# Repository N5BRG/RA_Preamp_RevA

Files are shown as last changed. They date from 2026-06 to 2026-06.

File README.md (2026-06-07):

# RA_Preamp_RevA

Copyright (c) 2026 Robert S. Stricklin Jr

This hardware design is licensed under the CERN Open Hardware Licence Version 2 - Permissive (CERN-OHL-P-2.0).

You may obtain a copy of the license in the `LICENSE` file included with this repository.

## Overview

This design is a Radio Astronomy Preamplifier intended for operation at 1420 MHz, which is approximately the frequency of the neutral hydrogen spectral line produced by the hyperfine spin-flip transition of hydrogen atoms in space. This signal is commonly referred to as the **Hydrogen Line** or the **21-centimeter Hydrogen Line**.

The goal of this preamplifier is to provide the lowest practical noise figure while amplifying extremely low-level radio signals. Included in the design is a PIN diode switch that allows switching between the antenna input and an alternate path terminated with a precision 50-ohm reference resistor. This approach is similar to the Dicke switching technique developed by [Robert H. Dicke](https://en.wikipedia.org/wiki/Robert_H._Dicke) in the mid-1940s for microwave radiometry and receiver calibration.

For best performance, the preamplifier is powered from a low-noise 5-volt power supply (5.5 V maximum). The PIN diode switch is controlled by an external voltage of approximately 1.8 to 2.5 volts applied to the control input for the ON state (3.3 V maximum), and 0 V to -20 mV for the OFF state. The analog RF ground and the digital switching ground are separated to minimize the possibility of switching noise coupling into the RF signal path.

The total current required by the preamplifier is approximately 160 mA, although this value may vary somewhat with temperature and component tolerances. At 5 volts and 160 mA, the power dissipation is approximately 800 mW at 25°C, so good thermal management should be considered when mounting the preamplifier in an enclosure.

The PCB is designed to plug into a power and control PCB. However, because the power board is longer, it may be more practical to mount the boards side-by-side if the power board is used. To minimize noise, a low-noise linear voltage regulator is recommended.

A graph showing the noise figure versus frequency, along with the gain of the preamplifier, is included with the project files. These measurements were obtained using an HP 8970B Noise Figure Meter. The 1420 MHz noise figure is 0.46 dB and the gain is 40.11 dB.

## Amateur Radio Astronomy

This design was created to support the educational and scientific goals of the Society of Amateur Radio Astronomers (SARA). Additional information about SARA can be found at:

https://www.radio-astronomy.org/

Many of the ideas incorporated into this design were discussed during SARA's regular monthly Zoom meetings and educational activities.

If you enjoy physics, astronomy, radio astronomy, electronics, and scientific experimentation, please consider joining SARA and participating in its programs. SARA is an especially good opportunity for students and young people who are interested in science, engineering, and technology. Most participation is conducted online through video conference meetings.

## Acknowledgements

If you use KiCad, please consider making a donation to the project to help support the continuing development and distribution of this outstanding open-source electronic design software.

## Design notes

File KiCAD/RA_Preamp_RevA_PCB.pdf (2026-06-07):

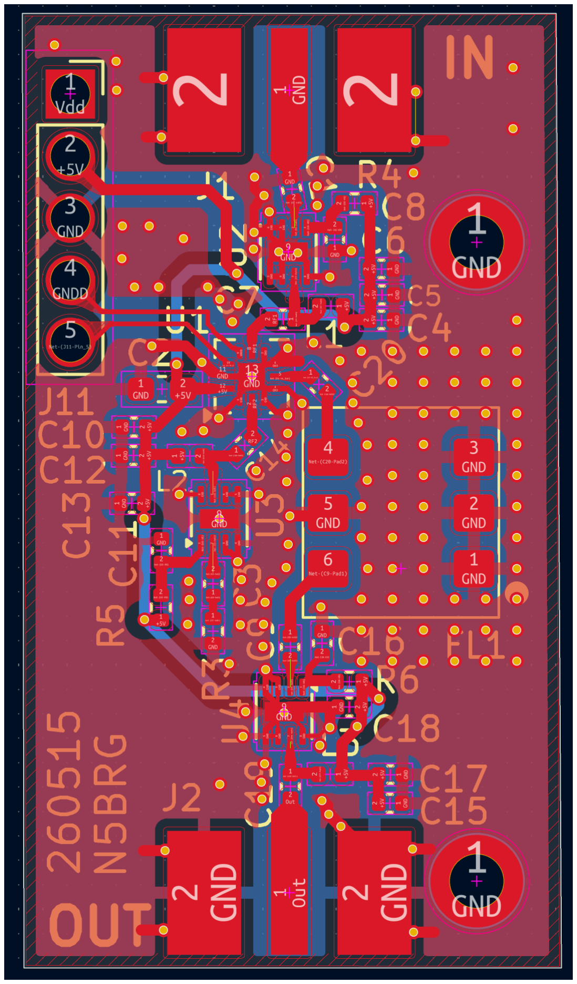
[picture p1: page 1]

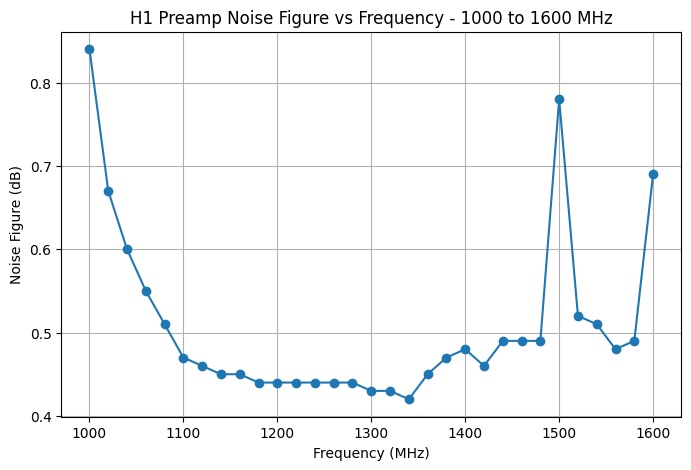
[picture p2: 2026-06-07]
H1_Preamp_NoiseFigure_vs_Frequency_REPLOT_zoom.jpg

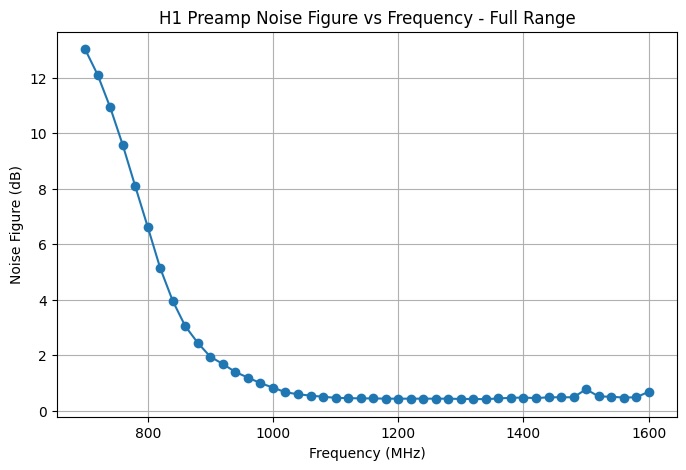
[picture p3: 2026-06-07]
H1_Preamp_NoiseFigure_vs_Frequency_REPLOT_full.jpg

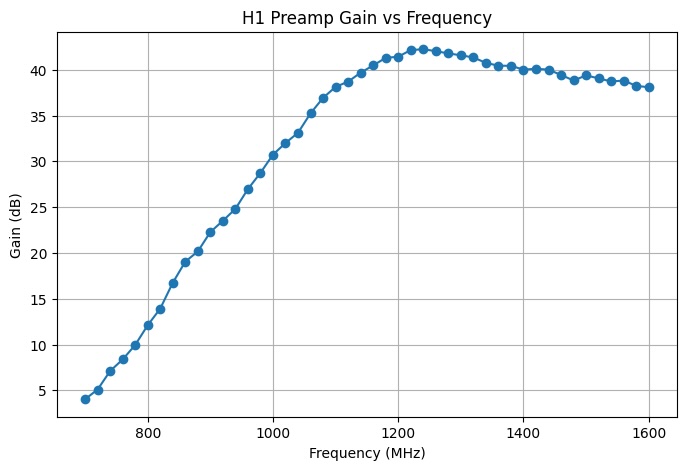
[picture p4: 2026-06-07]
H1_Preamp_Gain_vs_Frequency.jpg

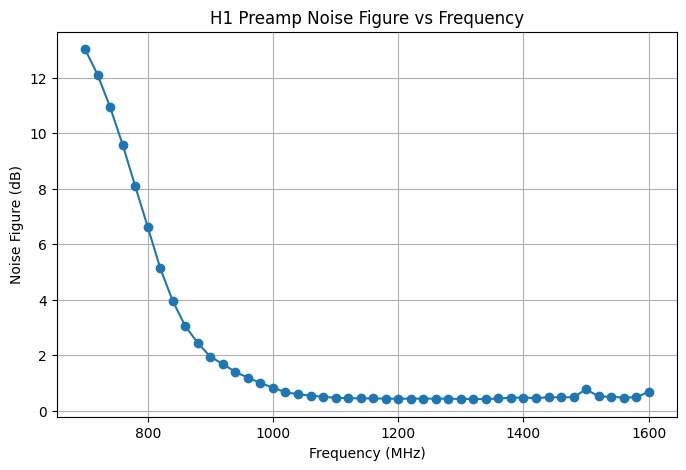
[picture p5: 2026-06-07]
H1_Preamp_NoiseFigure_vs_Frequency.jpg

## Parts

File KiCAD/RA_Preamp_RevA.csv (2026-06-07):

Source: | /Volumes/Public/Projects/KiCAD PCBs/H1_RF2_C/H1_RF2_C.kicad_sch
Date: | 2026-04-18T14:53:34
Tool: | Eeschema 9.99.0-5271-ge2e5514f9b
Generator: | /Applications/KiCad/KiCad.app/Contents/SharedSupport/plugins/bom_csv_grouped_by_value_with_fp.py
Component Count: | 34
Ref | Qnty | Value | Cmp name | Footprint | Description | Vendor | DNP
C1, C3, C7, C9, C14, C19 | 6 | 22p | C | Capacitor_SMD:C_0402_1005Metric | Unpolarized capacitor
C2 | 1 | 100p | C | Capacitor_SMD:C_0603_1608Metric_Pad1.08x0.95mm_HandSolder | Unpolarized capacitor
C4, C10, C15 | 3 | 10p | C | Capacitor_SMD:C_0402_1005Metric | Unpolarized capacitor
C5, C12, C17 | 3 | 1u | C | Capacitor_SMD:C_0402_1005Metric | Unpolarized capacitor
C6, C13, C18 | 3 | 100p | C | Capacitor_SMD:C_0402_1005Metric | Unpolarized capacitor
C8, C11, C16 | 3 | 0.1u | C | Capacitor_SMD:C_0402_1005Metric | Unpolarized capacitor
FL1 | 1 | SYBP-1420+ | SYBP-1420+ | Bob:PL-308 | Band Pass Filter 1250 to 1560 MHz
J1 | 1 | Antenna | Antenna | Bob:SMA_WIDE_GND_EdgeMount_Small | Antenna
J2 | 1 | SMA | Conn_Coaxial_Small | Bob:SMA_WIDE_GND_EdgeMount_Small | small coaxial connector (BNC, SMA, SMB, SMC, Cinch/RCA, LEMO, ...)
J11 | 1 | Conn_01x04_Pin | Conn_01x05_Pin | Connector_PinSocket_2.54mm:PinSocket_1x05_P2.54mm_Vertical | Generic connector, single row, 01x05, script generated
L1, L2, L3 | 3 | 18n | L | Inductor_SMD:L_0402_1005Metric | Inductor
R3 | 1 | 50 | R | Resistor_SMD:R_0402_1005Metric | Resistor
R4, R5, R6 | 3 | 3.32K | R | Resistor_SMD:R_0402_1005Metric | Resistor
U1 | 1 | JSW2-63VHDRG+ | JSW2-63VHDRG+ | Bob:MT2140_With_polygons_custompads | SPDT RF Switch Insuration loss 0.4 dB @ 3G
U2, U3, U4 | 3 | QPL9547 | QPL9547 | Package_DFN_QFN:DFN-8-1EP_2x2mm_P0.5mm_EP0.8x1.6mm | 100-6000MHz RF/IF +19.5dB gain block, DFN-8

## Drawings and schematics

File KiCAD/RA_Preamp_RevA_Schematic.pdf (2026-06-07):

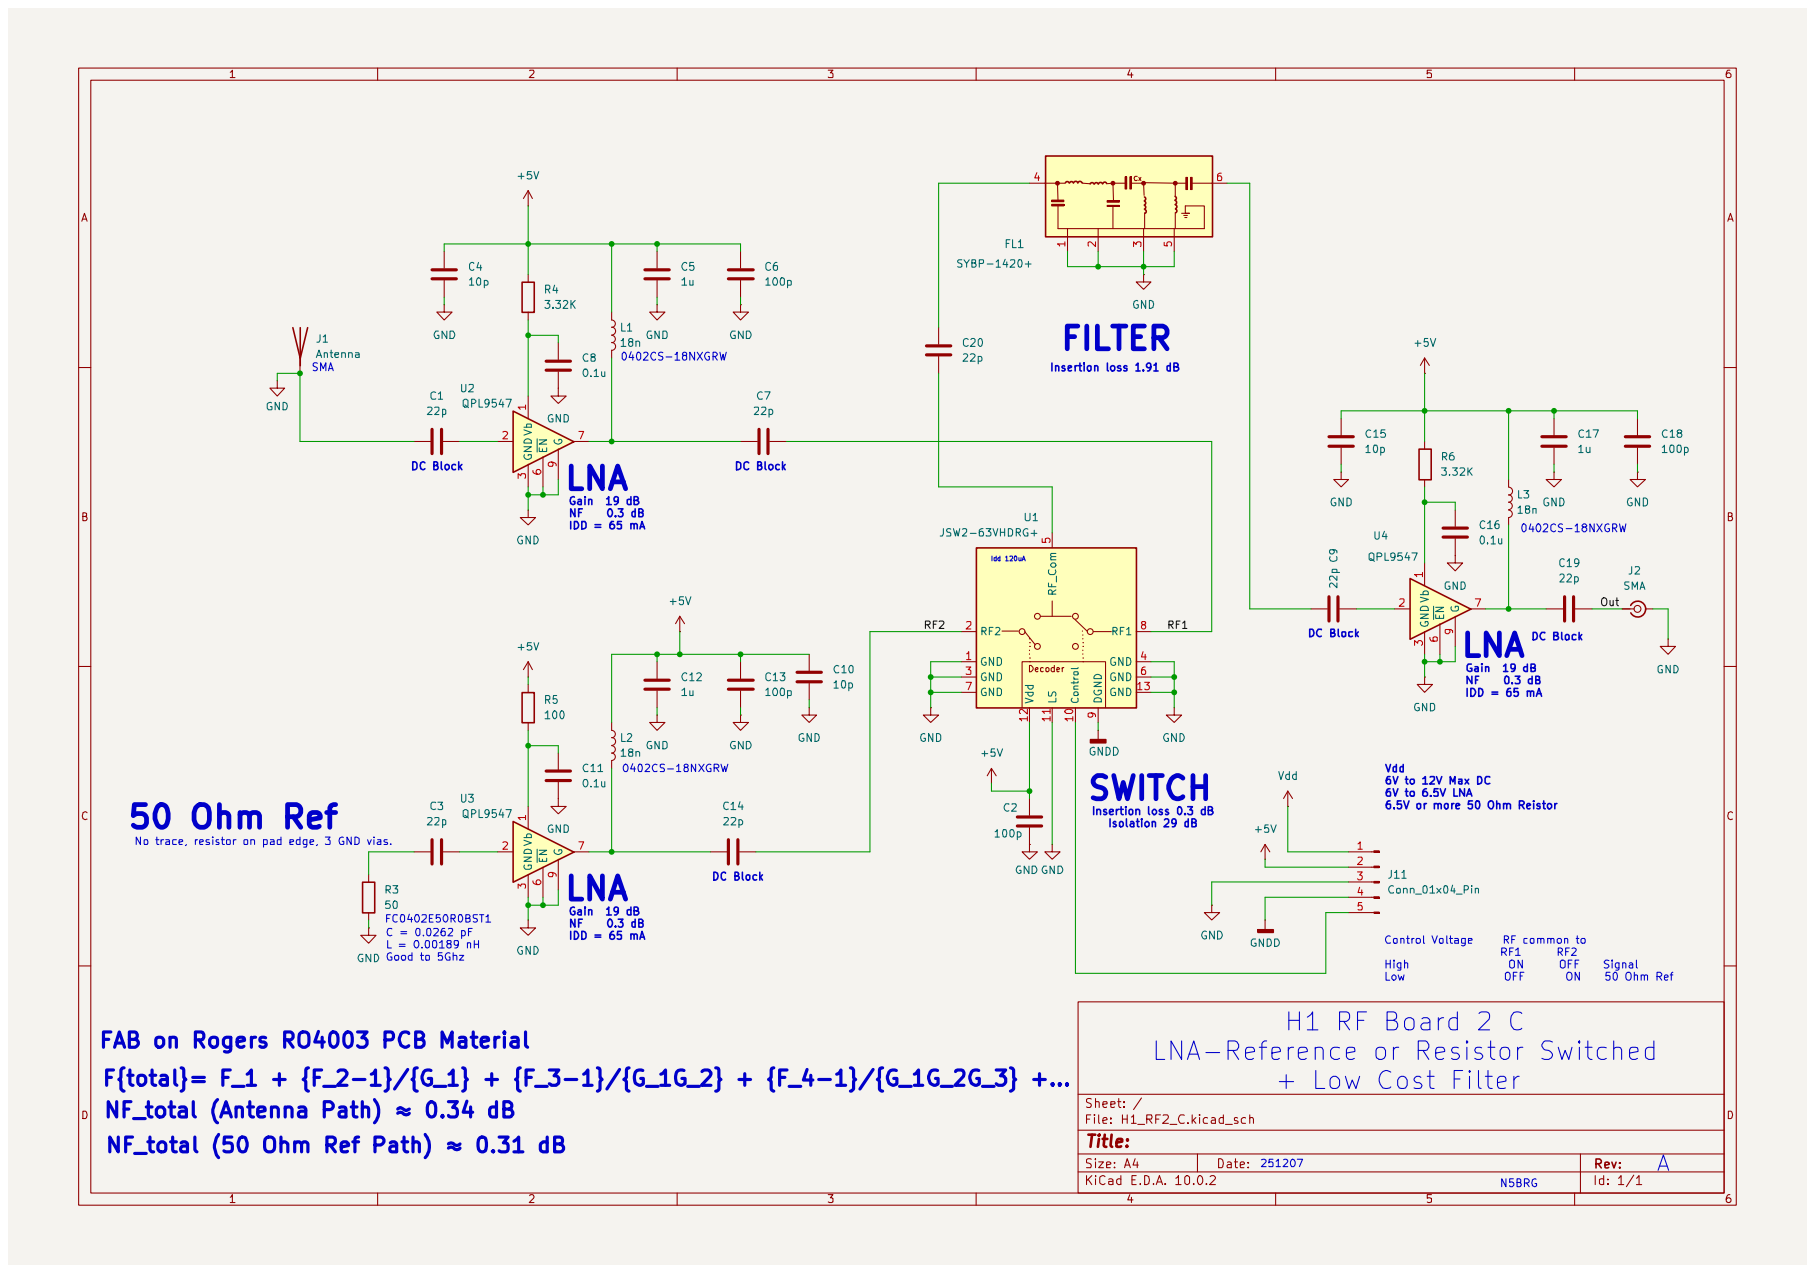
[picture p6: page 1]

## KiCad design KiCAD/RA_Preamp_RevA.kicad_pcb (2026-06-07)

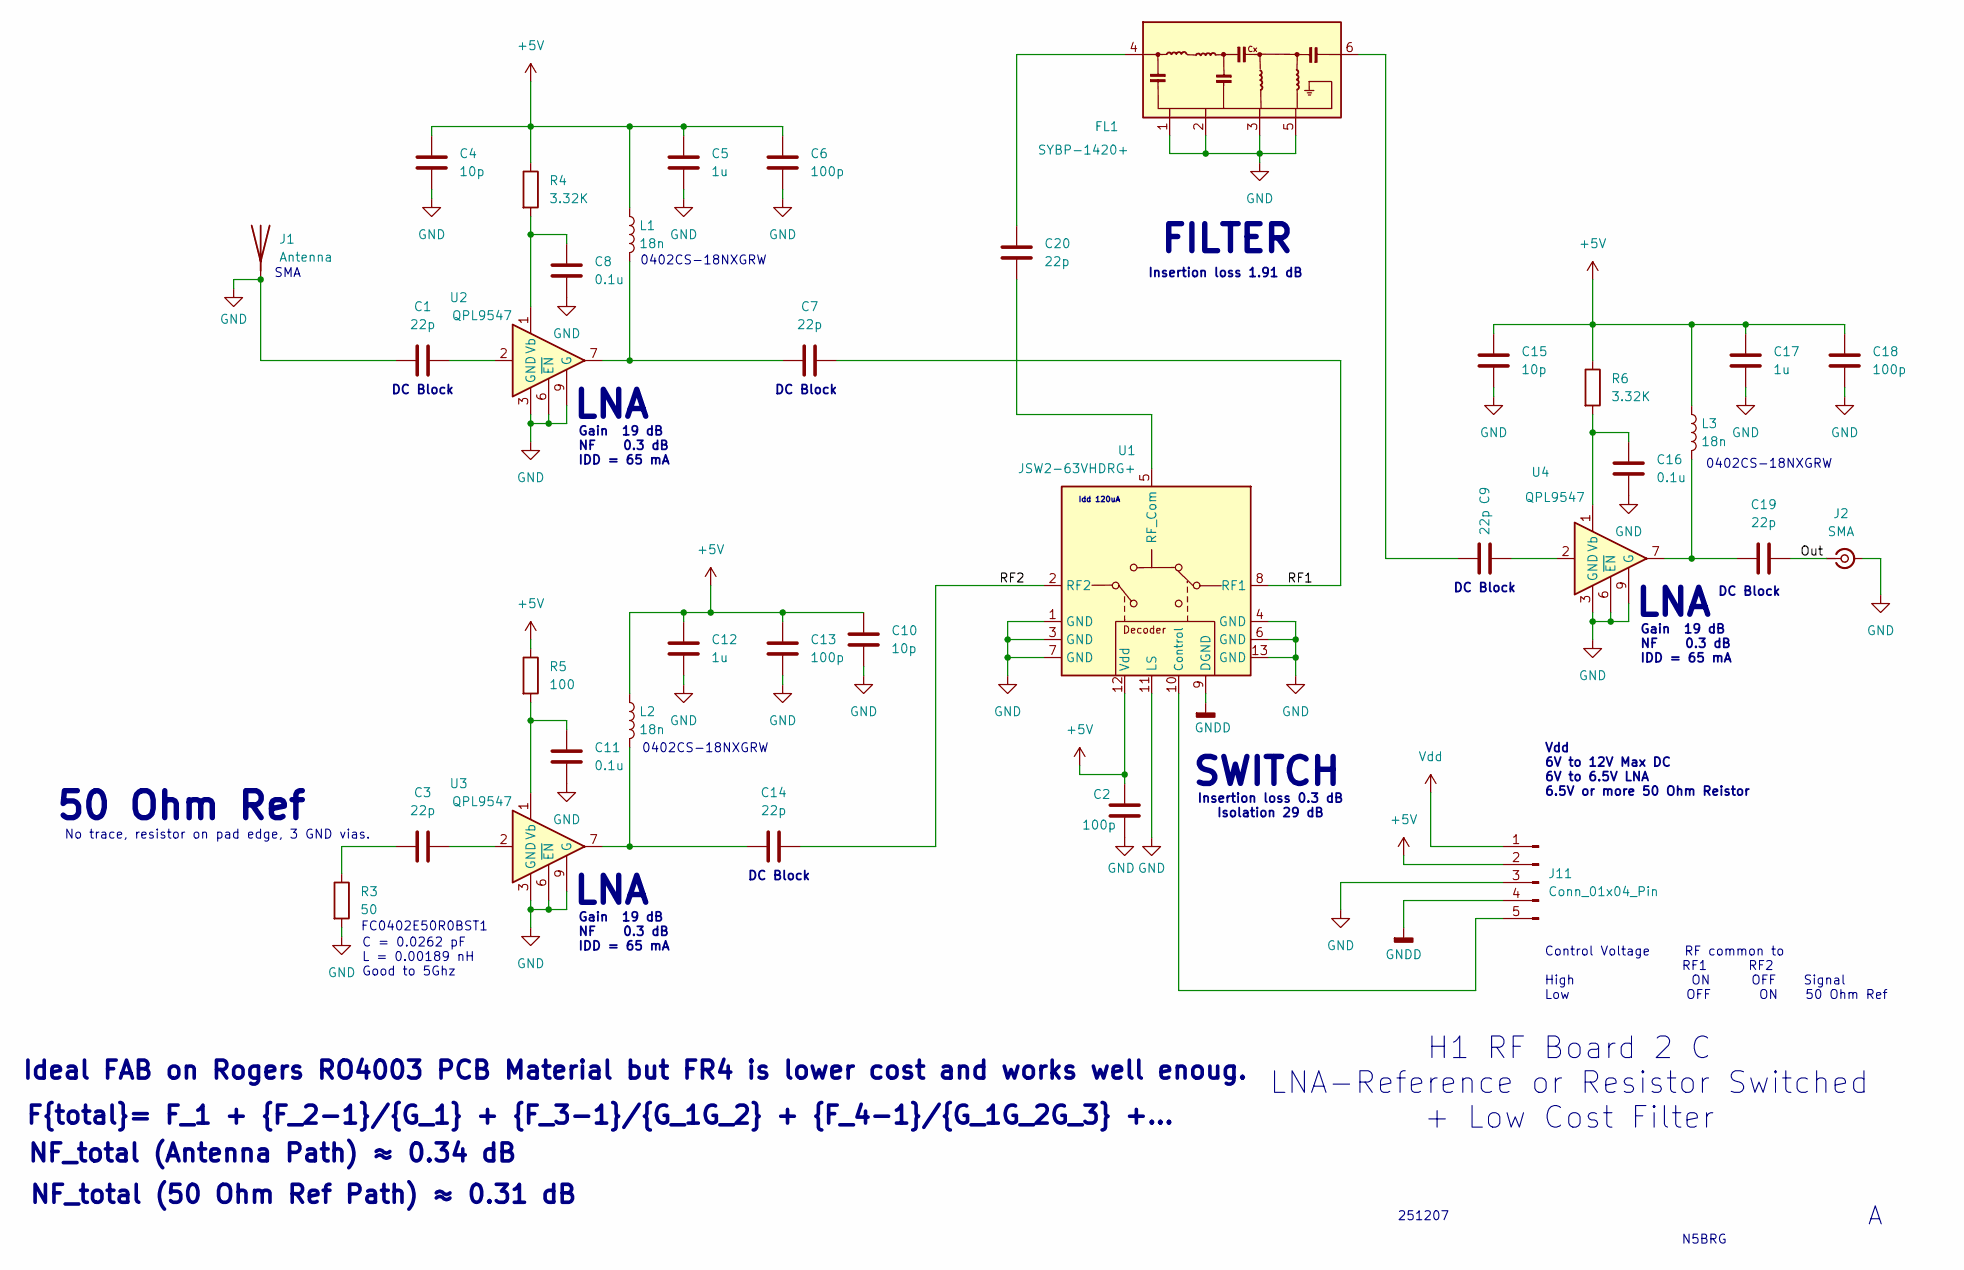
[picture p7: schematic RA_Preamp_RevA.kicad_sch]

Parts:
C1, C3, C7, C9, C14, C19, C20: 22p; C_0402_1005Metric; MPN 0402YK220FBWTR
C2: 100p; C_0603_1608Metric_Pad1.08x0.95mm_HandSolder; MPN GCM1555C1H101FA16J
C4, C10, C15: 10p; C_0402_1005Metric; MPN C0402C100K4RACAUTO
C5, C12, C17: 1u; C_0402_1005Metric; MPN C0402C105K4PACTU
C6, C13, C18: 100p; C_0402_1005Metric; MPN GCM1555C1H101FA16J
C8, C11, C16: 0.1u; C_0402_1005Metric; MPN CC0402KRX7R7BB104
FL1: SYBP-1420+; PL-308; MPN Do Not Populate
J1: Antenna; SMA_WIDE_GND_EdgeMount_Small; MPN SMA Connector Board Edge
J2: SMA; SMA_WIDE_GND_EdgeMount_Small; MPN TBD SMA Connector Board Edge
J11: Conn_01x04_Pin; PinSocket_1x05_P2.54mm_Vertical; MPN 1001-0-15-15-30-27-04-0 (5X)
L1, L2, L3: 18n; L_0402_1005Metric; MPN 0402CS-18NXGRW
R3: 50; R_0402_1005Metric; MPN FC0402E50R0BST1
R4, R6: 3.32K; R_0402_1005Metric; MPN RC0402JR-073K3L
R5: 100; R_0402_1005Metric; MPN RC0402JR-073K3L
U1: JSW2-63VHDRG+; MT2140_With_polygons_custompads; MPN JSW2-63VHDRG+
U2, U3, U4: QPL9547; DFN-8-1EP_2x2mm_P0.5mm_EP0.8x1.6mm; MPN QPL9547TR7

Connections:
+5V: C2.2, C4.2, C5.2, C6.2, C10.2, C12.2, C13.2, C15.2, C17.2, C18.2, J11.2, L1.1, L2.1, L3.1, R4.1, R5.1, R6.1, U1.12 (Vdd)
/Out: C19.2, J2.1 (In)
/RF1: C7.2, U1.8 (RF1)
/RF2: C14.2, U1.2 (RF2)
GND: C1.1, C2.1, C4.1, C5.1, C6.1, C8.1, C10.1, C11.1, C12.1, C13.1, C15.1, C16.1, C17.1, C18.1, FL1.1 (GND), FL1.2 (GND), FL1.3 (GND), FL1.5 (GND), J1.1 (A_1), J2.2 (Ext), J11.3, R3.2, U1.1 (GND), U1.3 (GND), U1.4 (GND), U1.6 (GND), U1.7 (GND), U1.11 (LS), U1.13 (GND), U2.3 (GND), U2.4 (GND), U2.5 (GND), U2.6 (~EN), U2.8 (GND), U2.9 (GND), U3.3 (GND), U3.4 (GND), U3.5 (GND), U3.6 (~EN), U3.8 (GND), U3.9 (G), U4.3 (GND), U4.4 (GND), U4.5 (GND), U4.6 (~EN), U4.8 (GND), U4.9 (GND); also elsewhere on the board
GNDD: J11.4, U1.9 (DGND)
unnamed: C1.2, U2.2
unnamed: C3.1, R3.1
unnamed: C3.2, U3.2
unnamed: C7.1, L1.2, U2.7
unnamed: C9.1, FL1.6
unnamed: C9.2, U4.2
unnamed: C14.1, L2.2, U3.7
unnamed: C19.1, L3.2, U4.7
unnamed: C20.2, FL1.4
unnamed: J11.5, U1.10 (Control)
unnamed: C20.1, U1.5 (RF_Com)
unnamed: C8.2, R4.2, U2.1 (Vb)
unnamed: C11.2, R5.2, U3.1 (Vb)
unnamed: C16.2, R6.2, U4.1 (Vb)
Vdd: J11.1

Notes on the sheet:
F{total}= F_1 + {F_2-1}/{G_1} + {F_3-1}/{G_1G_2} + {F_4-1}/{G_1G_2G_3} +...
FILTER
N5BRG
0402CS-18NXGRW
DC Block
LNA
251207
FC0402E50R0BST1
Gain 19 dB NF 0.3 dB IDD = 65 mA
NF_total (50 Ohm Ref Path) ≈ 0.31 dB
SMA
No trace, resistor on pad edge, 3 GND vias.
Vdd 6V to 12V Max DC 6V to 6.5V LNA 6.5V or more 50 Ohm Reistor
Idd 120uA
50 Ohm Ref
Insertion loss 1.91 dB
Insertion loss 0.3 dB Isolation 29 dB
NF_total (Antenna Path) ≈ 0.34 dB
C = 0.0262 pF L = 0.00189 nH Good to 5Ghz
SWITCH
H1 RF Board 2 C LNA-Reference or Resistor Switched + Low Cost Filter
Ideal FAB on Rogers RO4003 PCB Material but FR4 is lower cost and works well enoug.
Control Voltage RF common to RF1 RF2 High ON OFF Signal Low OFF ON 50 Ohm Ref

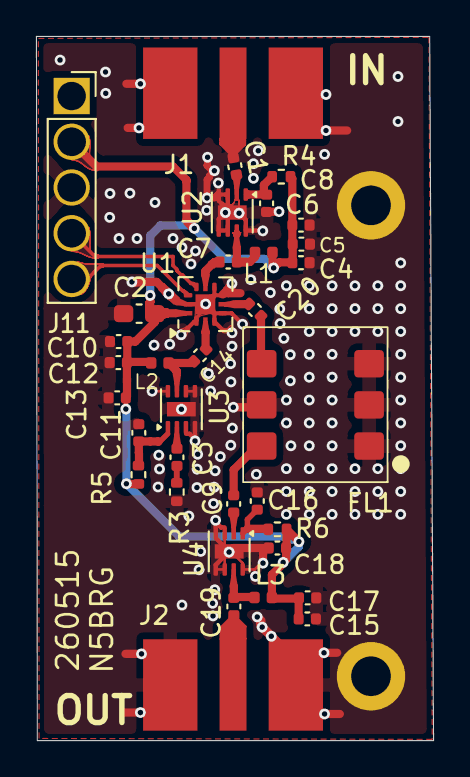
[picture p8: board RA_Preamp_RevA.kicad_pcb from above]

Board: 2 copper layers, 22.1 x 39.1 mm, 37 parts (0 on the bottom side), 20 nets.

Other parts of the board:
H10, H11: MountingHole_Pad; MountingHole_2.2mm_M2_DIN965_Pad

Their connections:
GND: H10.1 (1_1), H11.1 (1_1); also elsewhere on the board
